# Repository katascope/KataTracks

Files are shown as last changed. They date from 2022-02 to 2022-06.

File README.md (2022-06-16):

# KataTracks
The KataTracks system is three parts: The KataTracks software, the LightSuit, and the LightSuitAngel device.

## KataTracks
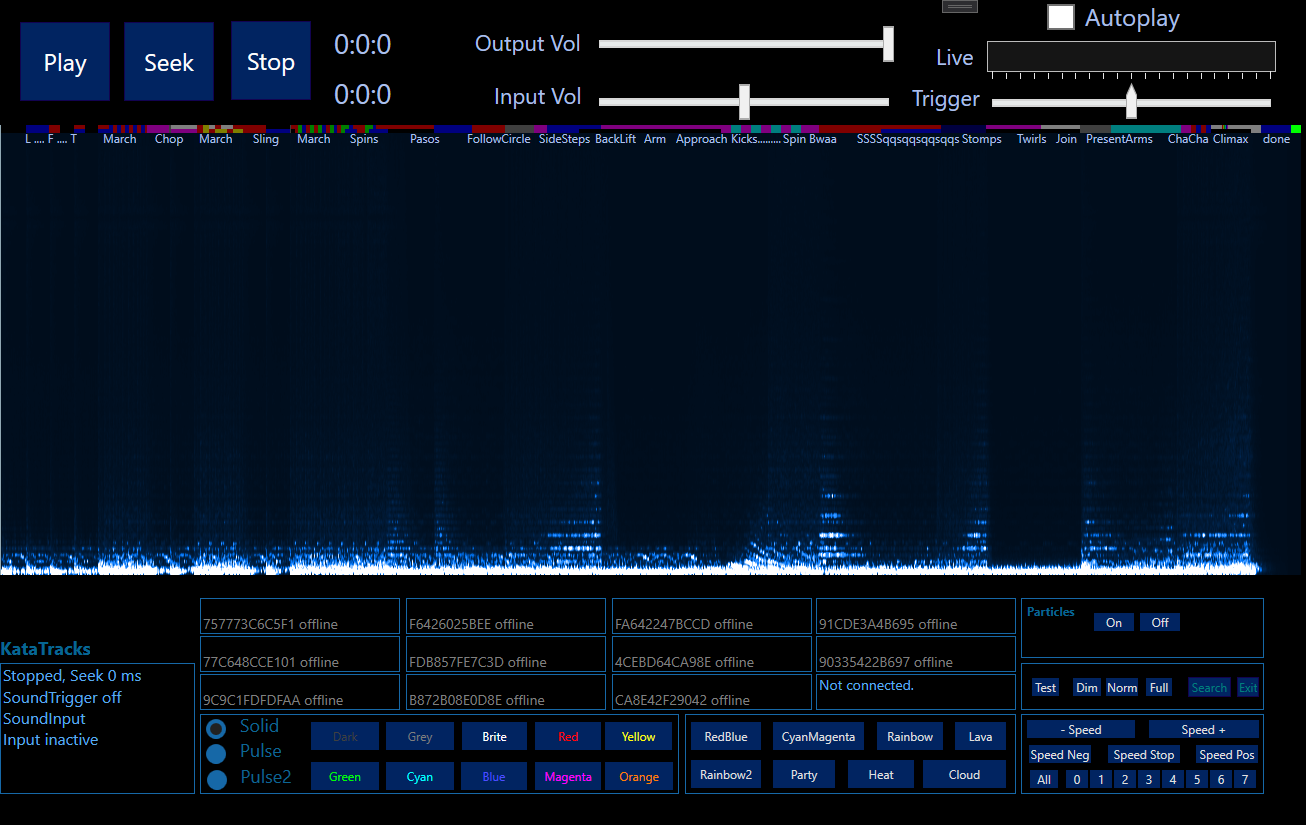
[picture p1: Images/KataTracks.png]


The KataTracks Application provides remote Bluetooth Low Energy (BLE) control over multiple LightSuits.

## LightSuit
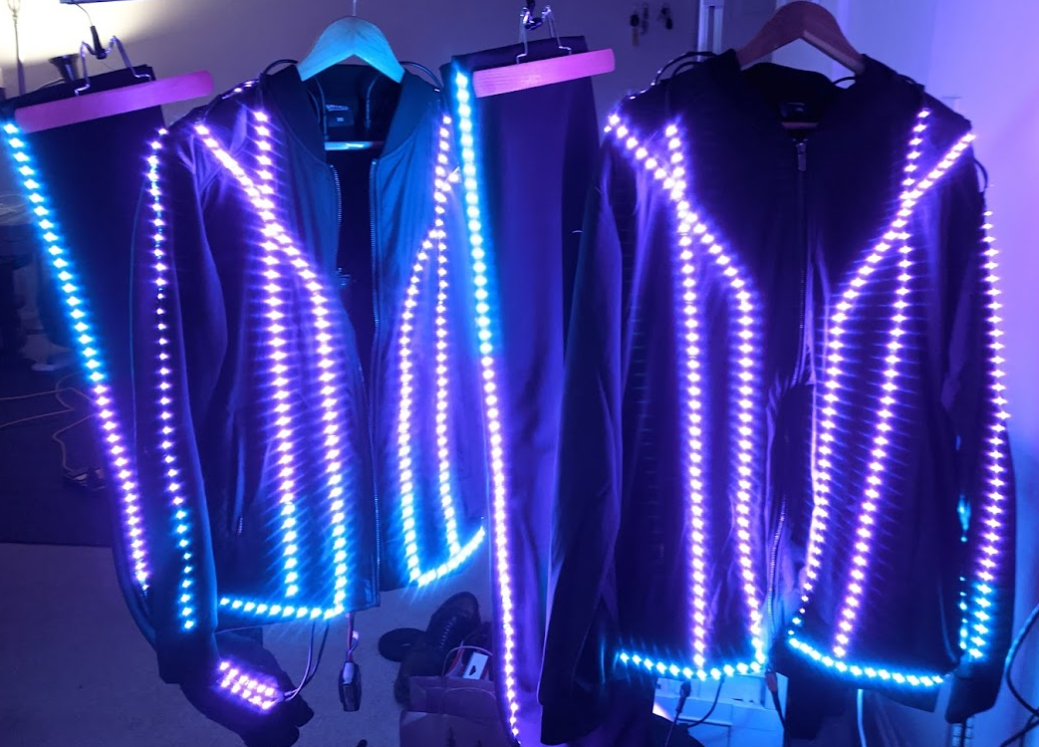
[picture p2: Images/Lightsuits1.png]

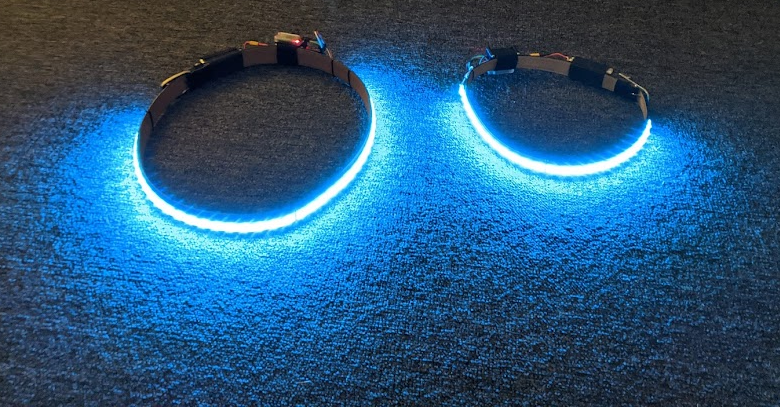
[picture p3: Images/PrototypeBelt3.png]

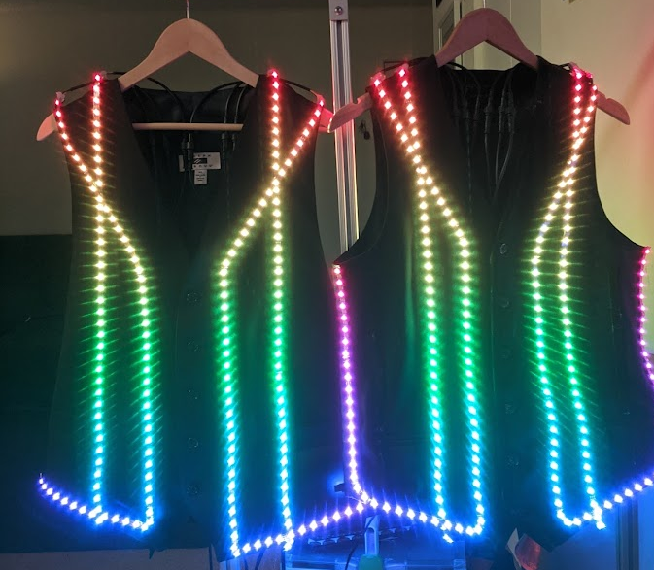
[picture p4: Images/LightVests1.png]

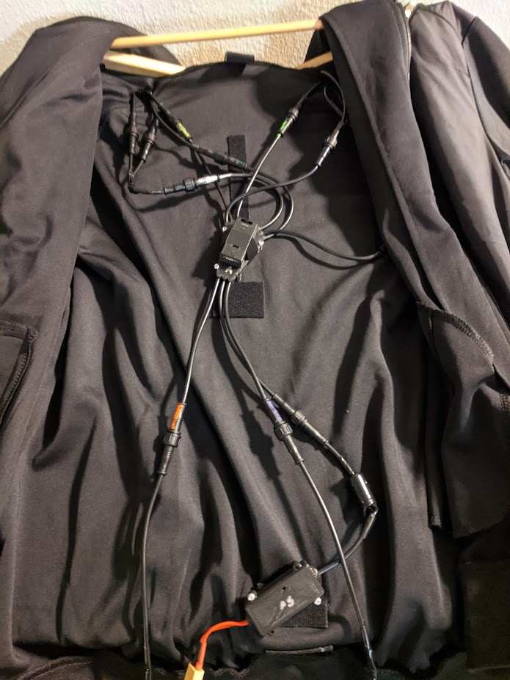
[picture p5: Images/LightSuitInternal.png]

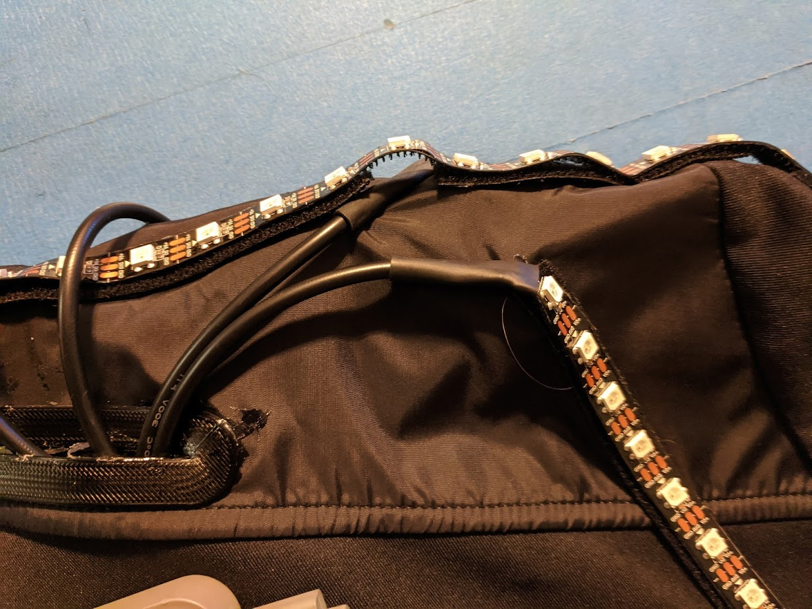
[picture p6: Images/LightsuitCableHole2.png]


Parts:
* BTF-LIGHTING WS2812B RGB 5050SMD Individual Addressable LED
* BTF-LIGHTING 3 Pin Electrical Connector 22AWG IP65 Male Female Connector
* Two-sided Velcro strip attached to suits
* Adhesive Velctro strip attached to LED strips
* Rubberized suit hole

Each LightSuit is a series of individually controlled addressable LED strips and LightSuitAngel. Velcro strips are attached to clothing, then to led strips. The velcro holds the strips together and connect at ends through 3-wire BTF connectors into the LightSuitAngel.

## LightSuitAngel
The LightSuitAngel devices provides 8-channels of control of LightSuit control. A 3d-printed case covers an Arduino Nano BLE device, using NeoPixel to run micro-second timed preprogrammed tracks.

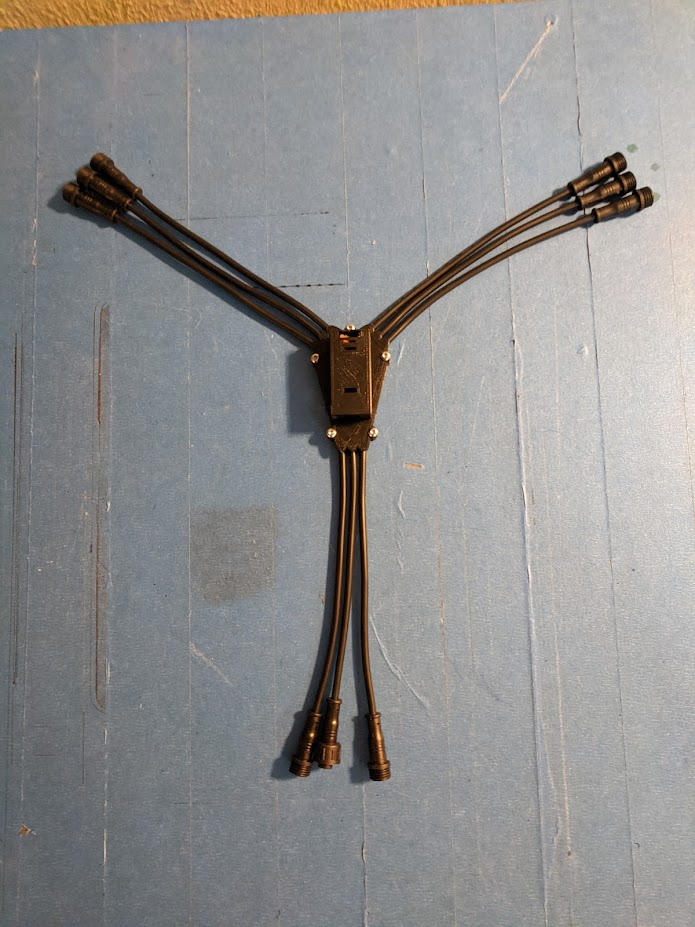
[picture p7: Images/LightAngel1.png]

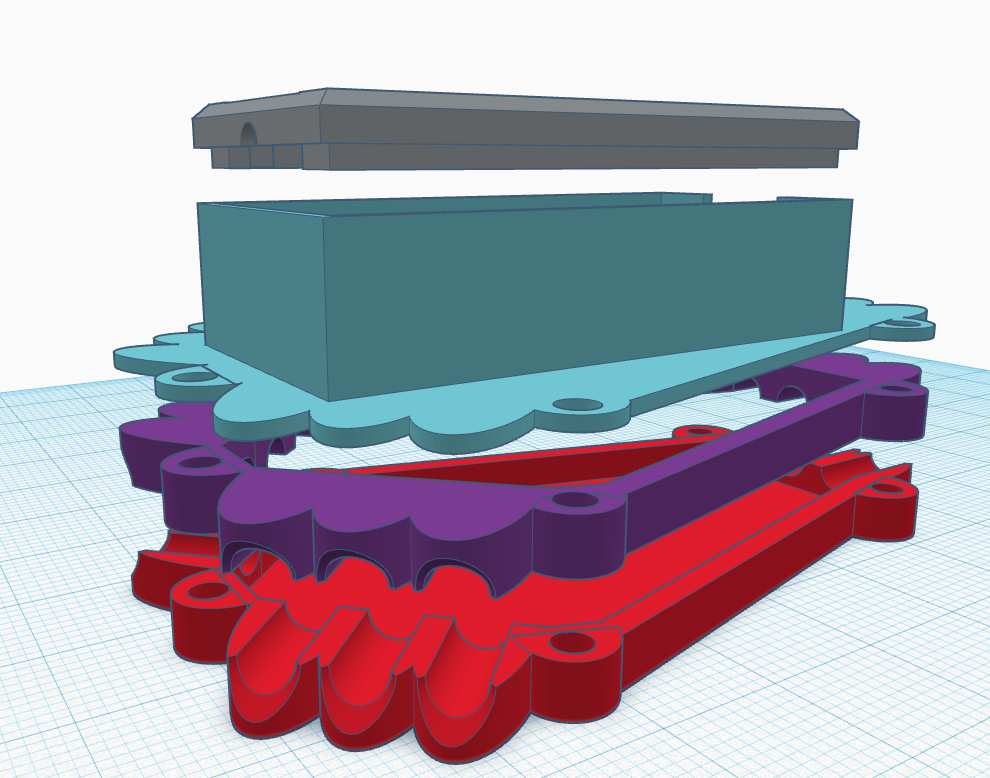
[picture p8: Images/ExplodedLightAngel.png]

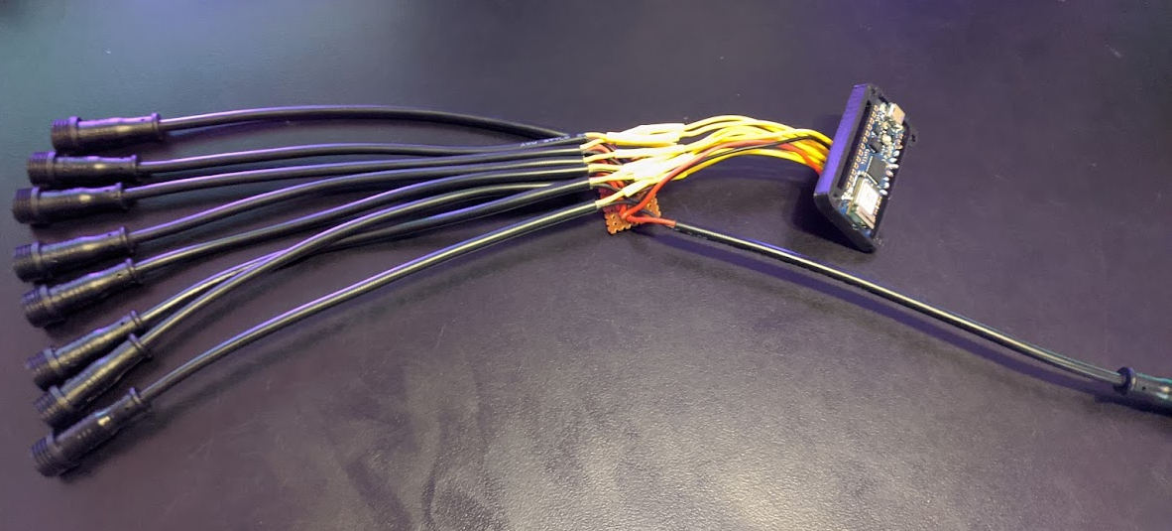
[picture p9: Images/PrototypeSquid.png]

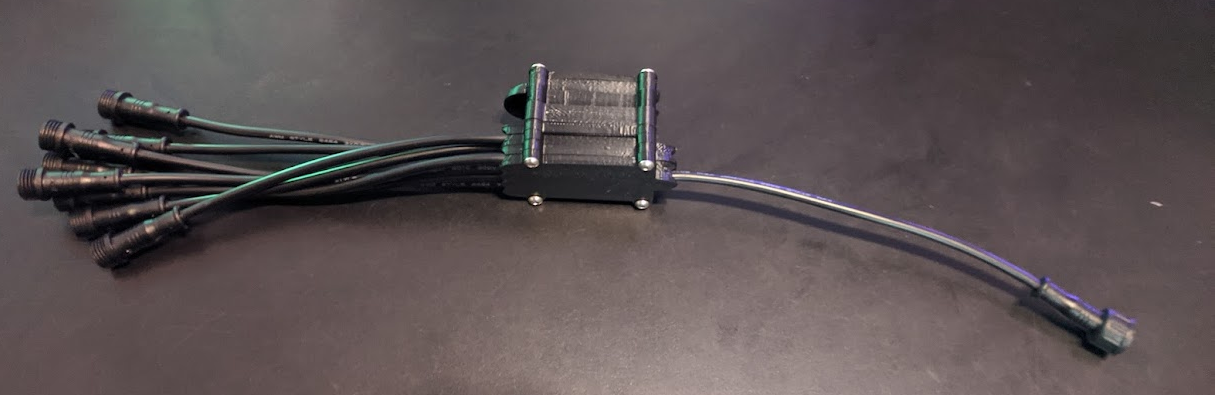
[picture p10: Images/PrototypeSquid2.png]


Parts
* Arduino Nano BLE
* BTF-LIGHTING WS2812B RGB 5050SMD Individual Addressable LED
* BTF-LIGHTING 3 Pin Electrical Connector 22AWG IP65 Male Female Connector
* LM2596S LM2596 Buck Converter 3A DC-DC 3-40V to 1.5-35v DC Voltage Regulator 
* 1000uF 50V Capacitor
* XT60 connector
* 25pcs DIP IC Chip Socket Adaptor
* M3 screws

Other simpler 1-channel devices can also be used with BTF splitters.

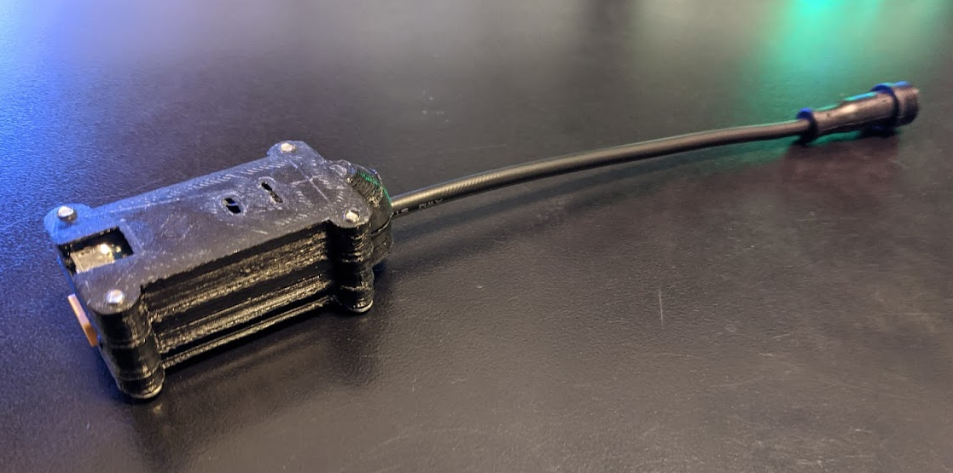
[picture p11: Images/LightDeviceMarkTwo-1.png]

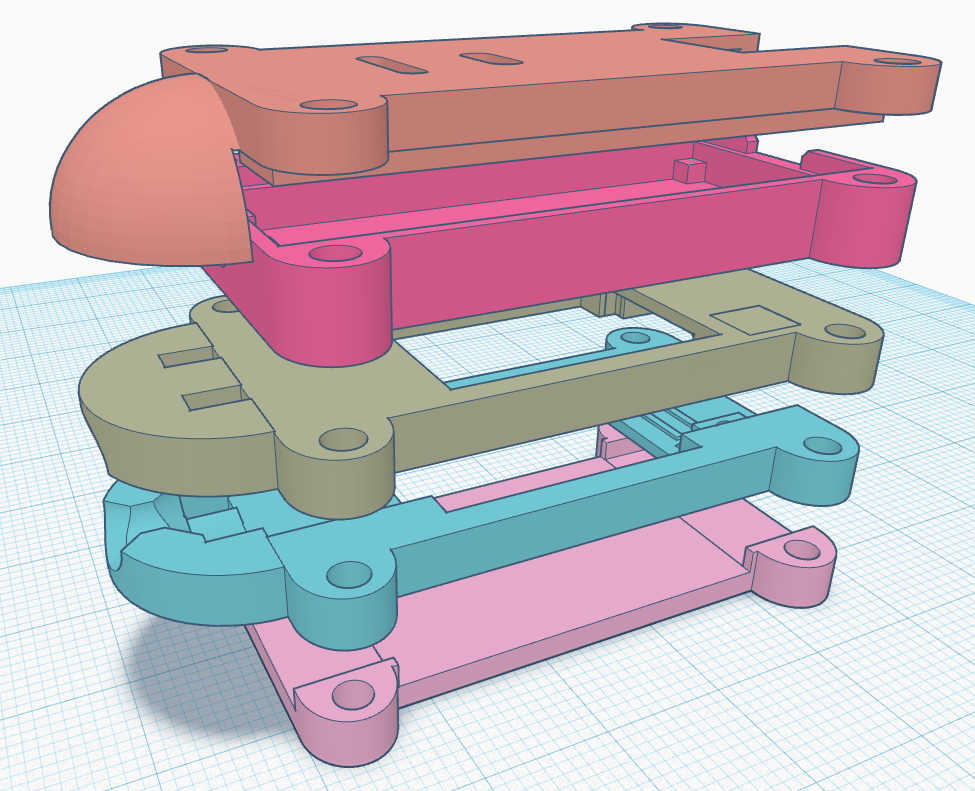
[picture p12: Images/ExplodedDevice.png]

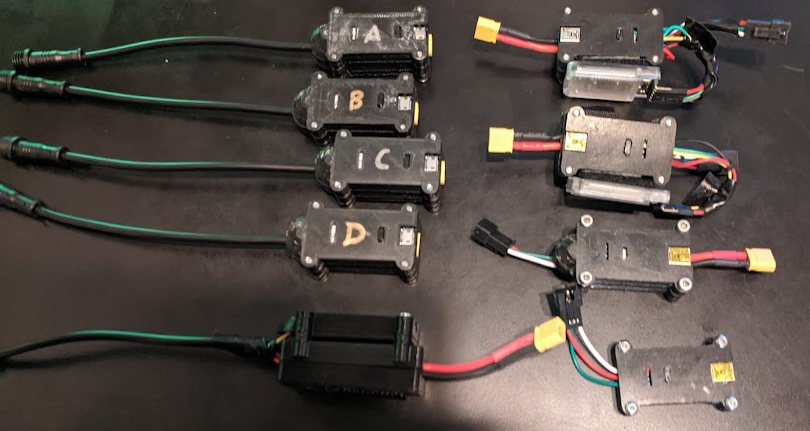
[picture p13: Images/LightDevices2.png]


In combination, the KataTracks system allows for multiple time-synchronized led light-suits to be used for performance dance.

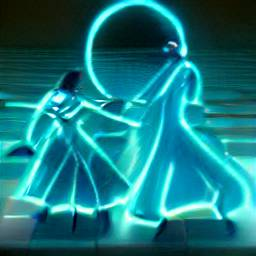
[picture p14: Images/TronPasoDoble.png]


Abandoned ideas:
* Using EL wire, too monochrome of effects.
* Using IMU for colors, too unpredictable during dance.
* Using regular Arduino Nano, Bluetooth modules cumbersome to attach.
* Using Arduino Nano IOT, timing was flaky.
* Playing music to theater, theater will have to provide sound.
* JST 3-wires, connectors have no tension or bend protection.

KataTracks is under the [MIT License](https://opensource.org/licenses/MIT)

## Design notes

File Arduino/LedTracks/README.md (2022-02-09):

# FastLEDTracks
Music Track system for FastLED

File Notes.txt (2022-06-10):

Devices, Bluetooth:
 AT+NAME=Lightsuit#
 AT+UART=9600,0,0
 AT+PSWD=...

Todo:
Build:
 Backup device
 Fix Burnt BEC
Research:
 KataTracks
  Postponed connecting
  "Shimmer test" for pre-show synchronicity
  Multi-threaded Reconnection ability
 Lightsuit
  Extension cables - need newtype connector
  X-hole connector, like leather/rubber?
 Device
  Redesign to protect Bluetooth module

# KataTracks
What it should be: Wireless light-suits precisely synchronized to events in the music.
Lightsuit.. Songtracksuit?

Mark 1 : 
 System: Arduino Nano
 Case: 3d-printed for Nano
 Power: XT30 connection (can adapt to XT60)
 Output: BTF-Lighting Connector
Mark 2 : Wireless
 Wireless: HC-05 Bluetooth
Mark 3
 System: Arduino Nano OR Pro Micro
 Case: 3d-printed for Nano
 Power: XT30 connection (can adapt to XT60)
 Output: BTF-Lighting Connector
 Wireless: HC-05 Bluetooth
Additions:
 Accelerometer
 128x32 OLED display

   Design Criteria:
    Audioreactive : The device must represent the dance music.
    Lead-Follow : The follow device can synchronize with the lead device.
    Simple : The device must be extremely easy to use once setup.
    Reliable : The software must work correctly during the dance.
     Care with overloading bluetooth buffer
     Startup 3 seconds for led safety
    Minimal : The device must strenously optimize RAM usage.
     PROGMEM for Track - Can expand without using RAM
     See: https://www.arduino.cc/reference/en/language/variables/utilities/progmem/
    Configurable : The code must be highly configurable by #DEFINE.
    Recoverable : The device should be able to recover from mistimings.
    Cheap : The device must be low cost and easy to produce.
    Portable : The device must be human wearable and untethered.
    Stable : The device must withstand repeated heavy use dancing.
    Subtle : Indirect lighting for led's, hazed frosted fogged.
    Compatible : The device must maximize use of standards.
     Arduino Nano : Standard microcontroller kit
     WS2811 : Addressable LED wire : Standard 3-wire connectors
     BTF-Lighting Connectors : Addressable 3-wire LED wire connectors
     Also used for power connector into arduino.
     XT-60 Battery connector with D-Sun BEC Voltage convert (3-cell 12v down to 5v)
      or 18650 Battery Shield case using 5-V output
     Thingiverse Case & plans
     ffmpeg for Spectrum Analysis
     HC-05 Bluetooth https://www.evelta.com/blog/instructions-to-set-bluetooth-module-hc05-password-using-arduino/
      AT+NAME?
      AT+NAME="LedLight"
      AT+PSWD="3838"
     Master+Slave BT bindings: https://www.instructables.com/Arduino-Bluetooth-Master-and-Slave-Using-Any-HC-05/
   Tradeoffs:
     Audio track setup does not have to be easy or quick.
     Different arduinos can be used.
     Different forms of power/battery can be used.
     Arduino Micro Pro can be used if possible instead of Arduino Nano
   Aesthetic Criteria:
     Tasteful : Use complex colors, avoid 'rgb rainbow land'
     Smooth : Fading color transitions over palette rotations
     Fade-To interpolated timing so endings match startings
   To create a spectrum analysis for use in creating the events:
     Use ffmpeg with a size of (song length * 10). ex 205 seconds * 10 = 2050x512 as below.
      ex. ffmpeg -i "game.m4a" -lavfi showspectrumpic=s=2050x512:color=4:scale=lin:stop=8000 gameLd.png
   Ideas:
    https://learn.sparkfun.com/tutorials/prototype-wearable-led-dance-harness/all
    https://learn.sparkfun.com/tutorials/motion-controlled-wearable-led-dance-harness
    https://learn.sparkfun.com/tutorials/hackers-in-residence---sound-and-motion-reactivity-for-wearables
   Radio: dw
    NRF24L01 https://www.instructables.com/Arduino-and-NRF24L01/
    RTF433 https://www.instructables.com/RF-315433-MHz-Transmitter-receiver-Module-and-Ardu/
   JY-MCU Bluetooth module communication example for Arduino.
    Connect RX_PIN to TX pin of the module,
    Connect TX_PIN to RX pin of the module.
   Set Bluetooth HC-05

   16k - For a bluetooth-enabled 300-addressableled-driving music-synchronized system

   //Accelerometer: https://electropeak.com/learn/interfacing-mma7361-accelerometer-module-with-arduino/

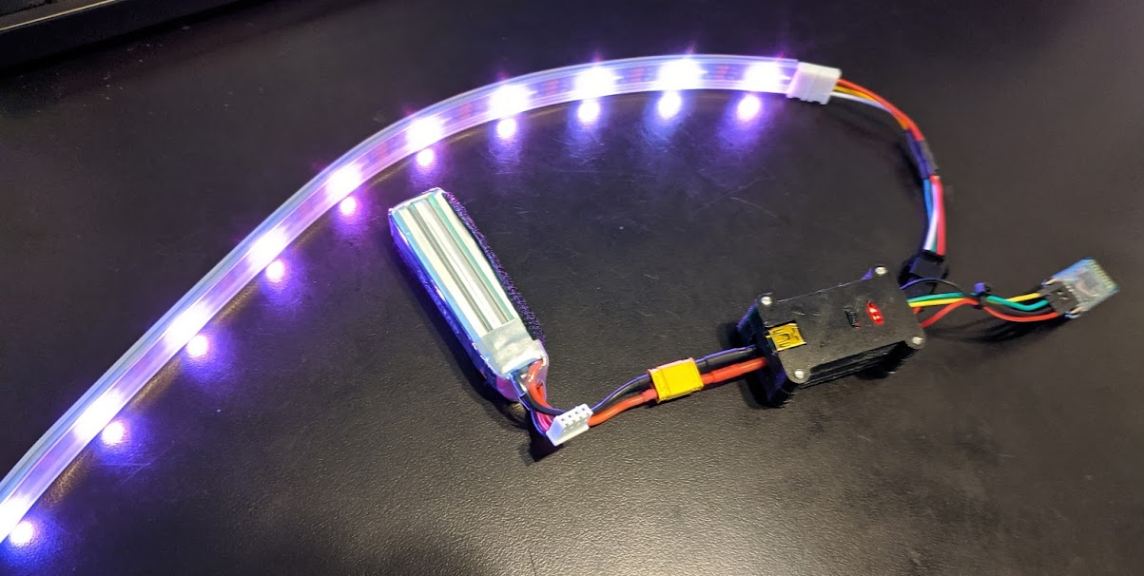
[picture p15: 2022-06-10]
Images/PrototypeBluetooth3.png

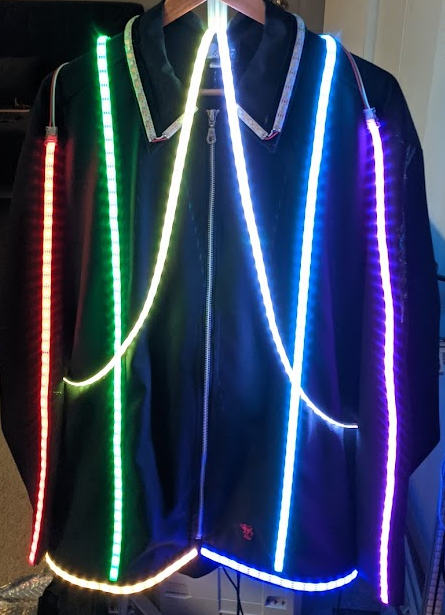
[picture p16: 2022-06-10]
Images/LightDeviceSquid-1.png

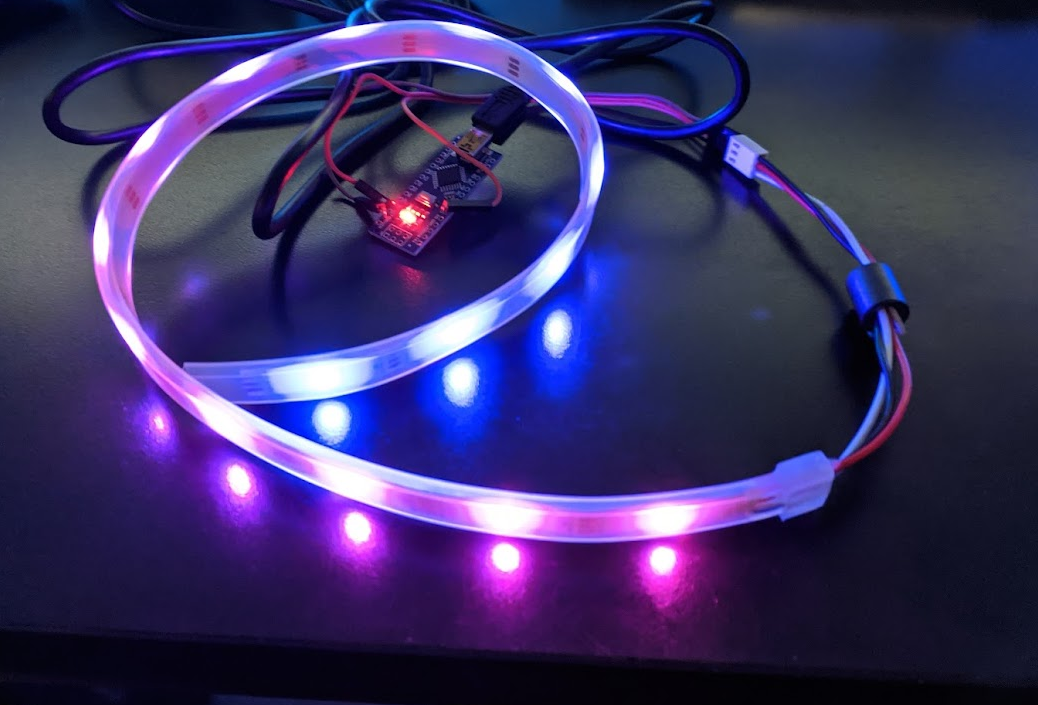
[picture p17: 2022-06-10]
Images/Prototype1.png

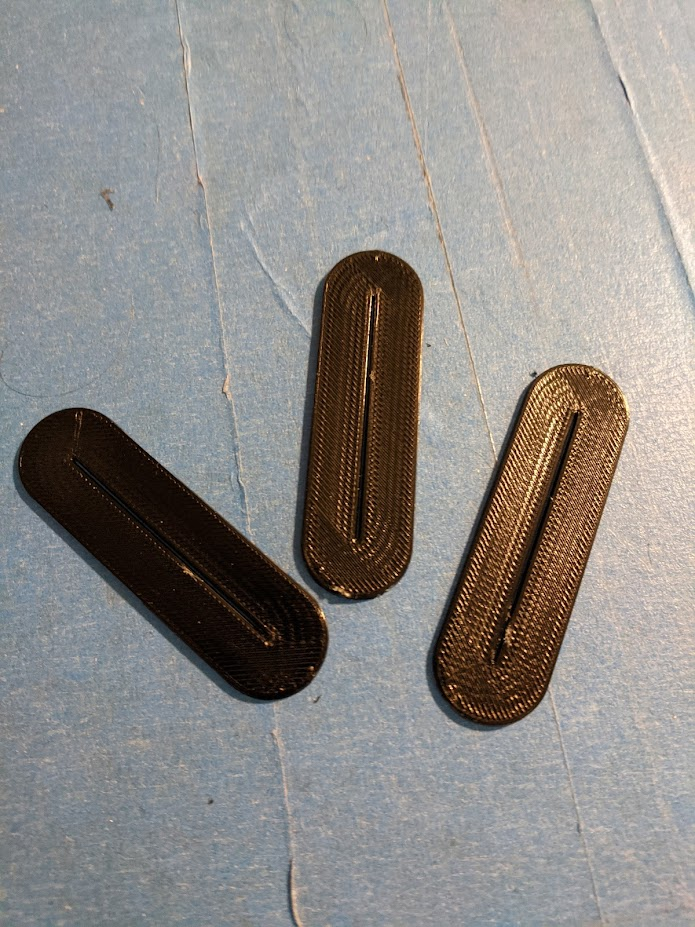
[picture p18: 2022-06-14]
Images/LightSuitCableHole1.png

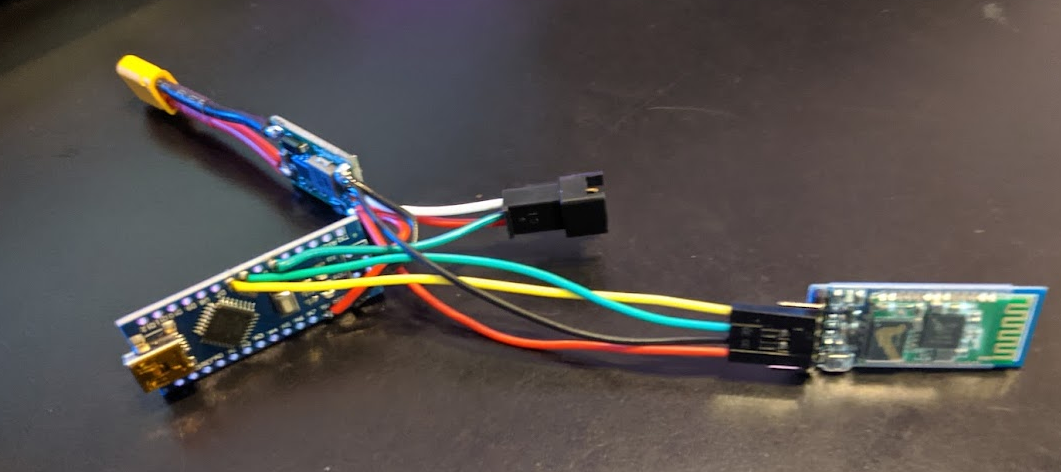
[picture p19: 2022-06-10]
Images/PrototypeBluetooth1.png

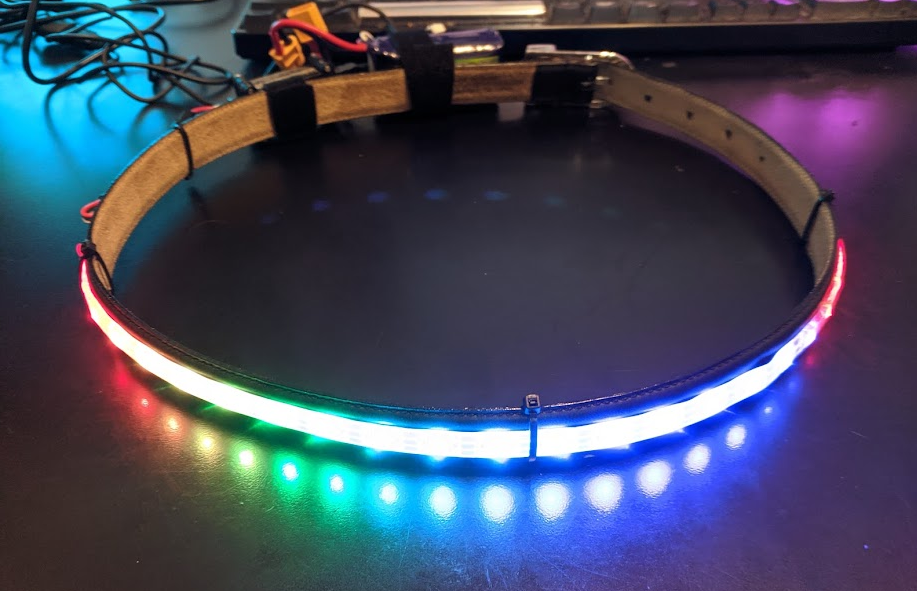
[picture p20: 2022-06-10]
Images/PrototypeBelt2.png

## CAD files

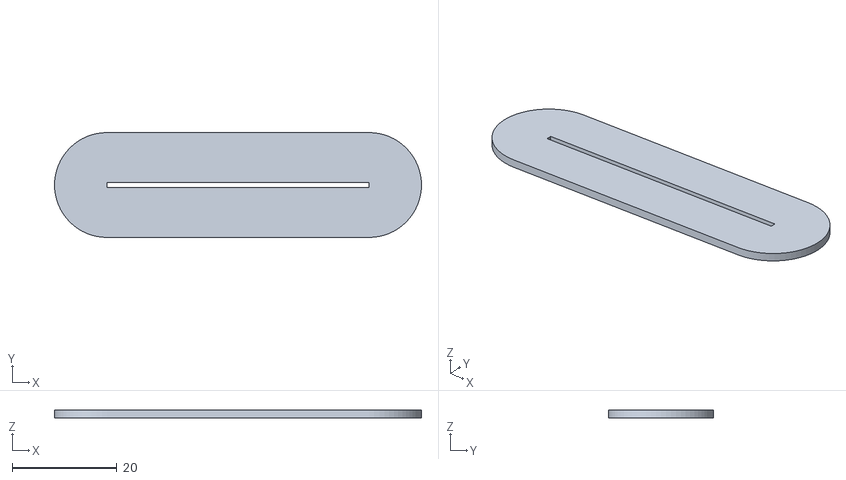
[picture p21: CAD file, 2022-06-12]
Hardware/STL/LightSuitCablePanel.stl
70.0 x 20.0 x 1.50

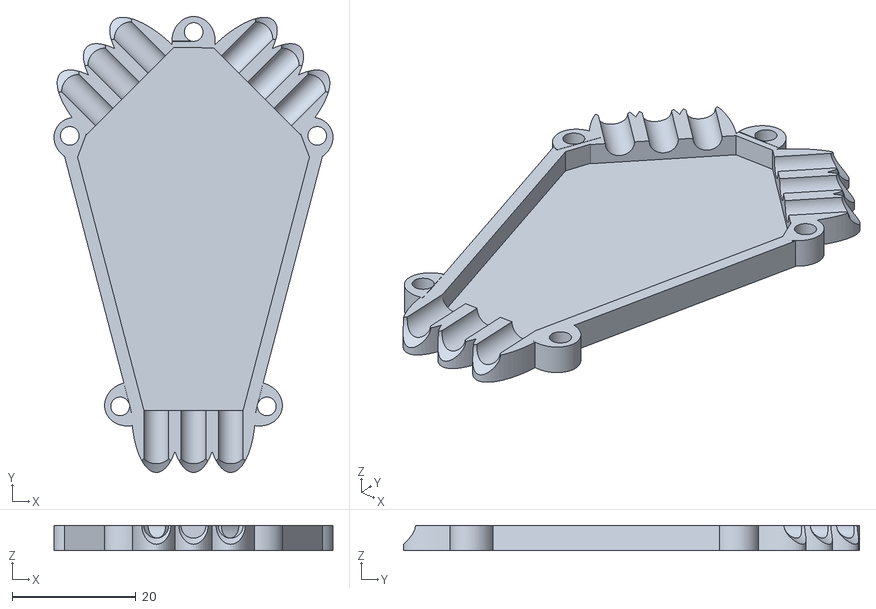
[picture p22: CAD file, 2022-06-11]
Hardware/STL/LightSuitAngel-Base.stl
45.0 x 73.6 x 4.03

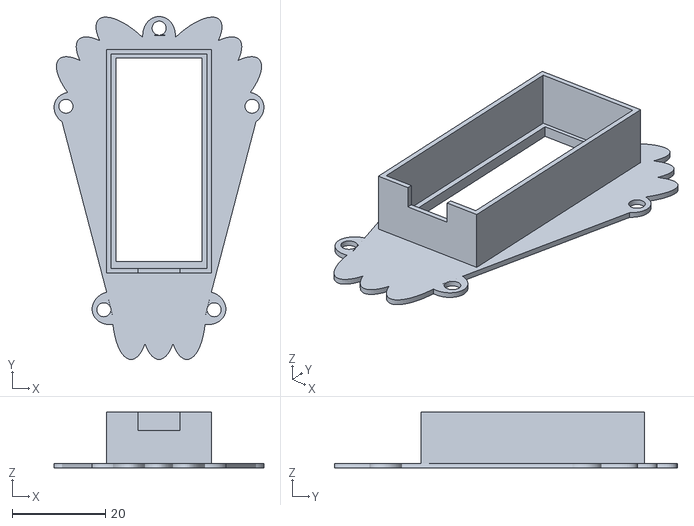
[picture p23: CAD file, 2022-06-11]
Hardware/STL/LightSuitAngel-Case.stl
45.0 x 73.6 x 12.0

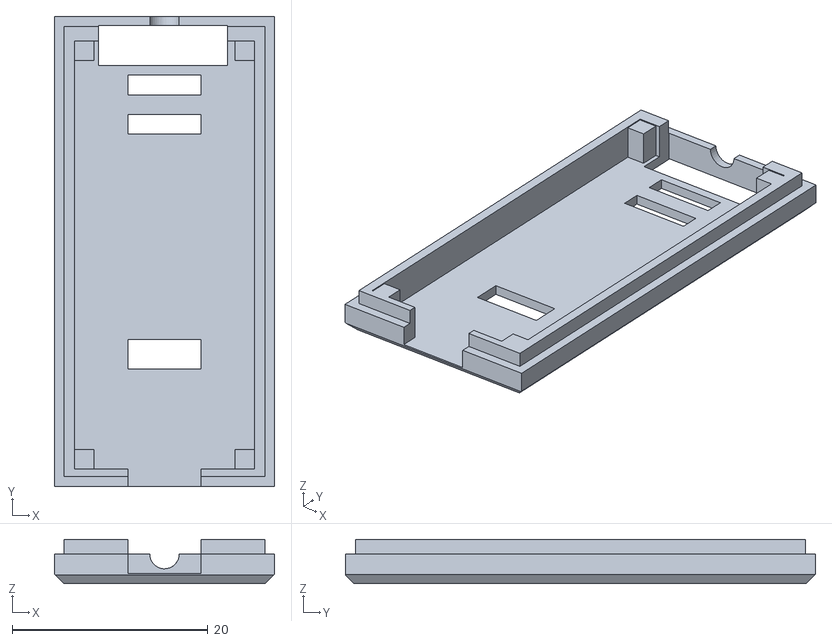
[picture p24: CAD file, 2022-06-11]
Hardware/STL/LightSuitAngel-Lid.stl
22.5 x 48.0 x 4.50

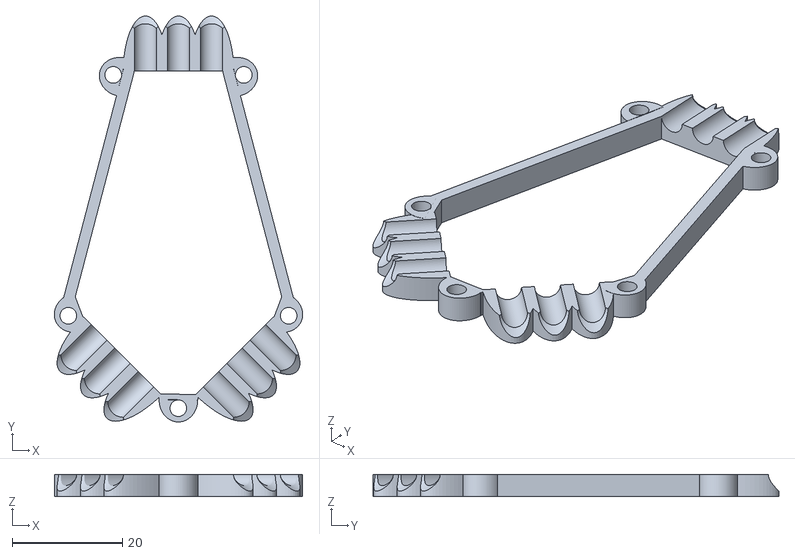
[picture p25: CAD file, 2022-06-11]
Hardware/STL/LightSuitAngel-Grip.stl
45.0 x 73.6 x 4.03

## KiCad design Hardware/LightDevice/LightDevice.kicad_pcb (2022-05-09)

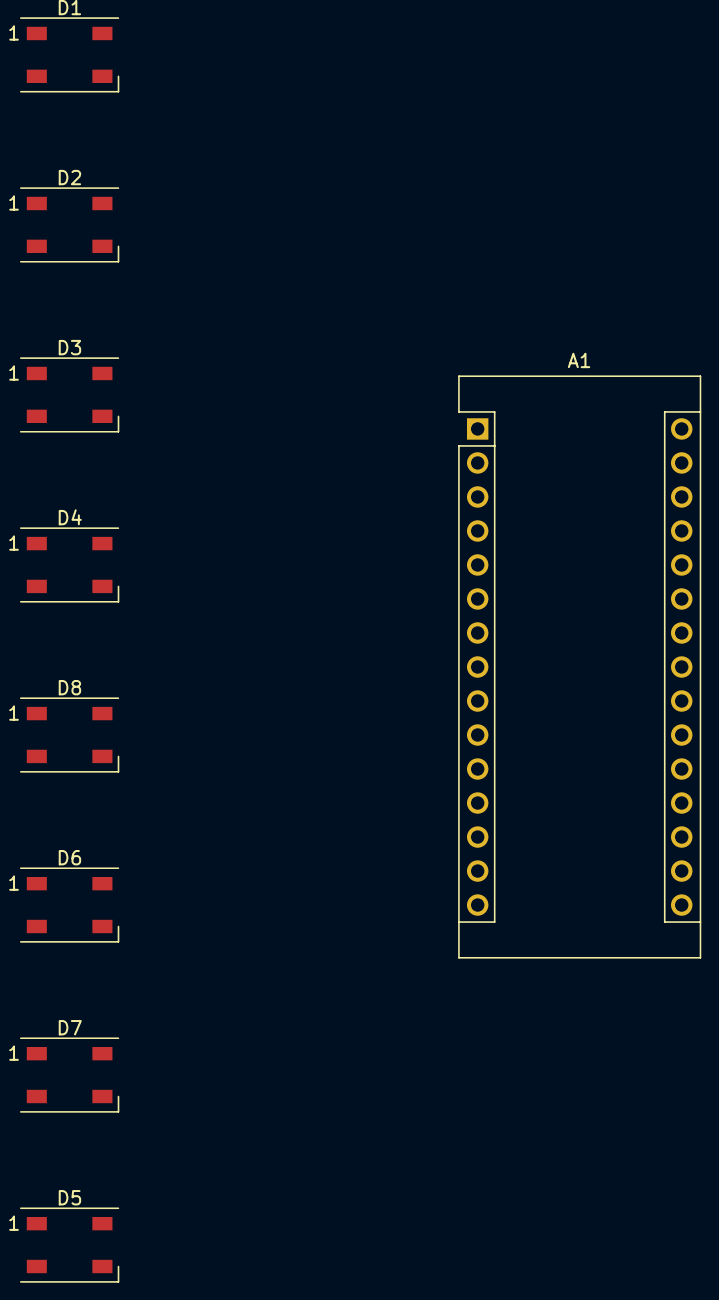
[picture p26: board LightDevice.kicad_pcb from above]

Board: 2 copper layers, 9 parts (0 on the bottom side), 10 nets, no tracks yet.

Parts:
A1: Arduino_Nano_v3.x; Arduino_Nano
D1, D2, D3, D4, D5, D6, D7, D8: WS2812B; LED_WS2812B_PLCC4_5.0x5.0mm_P3.2mm

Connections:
+5V: A1.27 (+5V), D1.3 (VSS), D2.3 (VSS), D3.3 (VSS), D4.3 (VSS), D5.3 (VSS), D6.3 (VSS), D7.3 (VSS), D8.3 (VSS)
GND: A1.29 (GND), D1.1 (VDD), D2.1 (VDD), D3.1 (VDD), D4.1 (VDD), D5.1 (VDD), D6.1 (VDD), D7.1 (VDD), D8.1 (VDD)
unnamed: A1.6 (D3), D1.4 (DIN)
unnamed: A1.7 (D4), D2.4 (DIN)
unnamed: A1.8 (D5), D3.4 (DIN)
unnamed: A1.9 (D6), D4.4 (DIN)
unnamed: A1.10 (D7), D5.4 (DIN)
unnamed: A1.11 (D8), D6.4 (DIN)
unnamed: A1.12 (D9), D7.4 (DIN)
unnamed: A1.13 (D10), D8.4 (DIN)

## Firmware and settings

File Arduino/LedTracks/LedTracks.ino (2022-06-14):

/*Copyright 6/14/2022 github/katascope
Permission is hereby granted, free of charge, to any person obtaining a copy of this software and associated documentation files (the "Software"), to deal in the Software without restriction, including without limitation the rights to use, copy, modify, merge, publish, distribute, sublicense, and/or sell copies of the Software, and to permit persons to whom the Software is furnished to do so, subject to the following conditions:
The above copyright notice and this permission notice shall be included in all copies or substantial portions of the Software.
THE SOFTWARE IS PROVIDED "AS IS", WITHOUT WARRANTY OF ANY KIND, EXPRESS OR IMPLIED, INCLUDING BUT NOT LIMITED TO THE WARRANTIES OF MERCHANTABILITY, FITNESS FOR A PARTICULAR PURPOSE AND NONINFRINGEMENT. IN NO EVENT SHALL THE AUTHORS OR COPYRIGHT HOLDERS BE LIABLE FOR ANY CLAIM, DAMAGES OR OTHER LIABILITY, WHETHER IN AN ACTION OF CONTRACT, TORT OR OTHERWISE, ARISING FROM, OUT OF OR IN CONNECTION WITH THE SOFTWARE OR THE USE OR OTHER DEALINGS IN THE SOFTWARE.*/
// LightDrive : A time-track event system for Addressable LED
// Purpose is for a wearable dance-synchronized lightsuit.
#include "Config.h"
#include "Fx.h"
#include "Track.h"
#include "Cmd.h"
#include "State.h"
#include "Devices.h"
static FxController fxController;

static unsigned long lastTimeDisplay = 0;

void setup() {
  Serial.begin(SERIAL_BAUD_RATE);
  Serial.print(DeviceName);
  Serial.print(F("Serial init: "));
  Serial.println(SERIAL_BAUD_RATE);
  
#if SYSTEM_NANO_33_BLE
  Serial.println(F("System: Arduino Nano 33 BLE"));
#elif SYSTEM_NANO_33_IOT
  Serial.println(F("System: Arduino Nano 33 IOT"));
#elif SYSTEM_UNO
  Serial.println(F("System: Arduino UNO"));
#elif SYSTEM_NANO
  Serial.println(F("System: Arduino Nano"));
#else
  Serial.println(F("System: UNKNOWN"));
#endif

#if ENABLE_MEMORYUSAGE
  Serial.println(F("MemoryUsage"));
  MEMORY_PRINT_STACKSIZE
  MEMORY_PRINT_HEAPSIZE
#endif  

#if ENABLE_NEOPIXEL
  Serial.println(F("Delaying 3 seconds for LEDs."));
  delay( 3000 ); // power-up safety delay
  neopixelSetup();
  for (int strip=0;strip<NUM_STRIPS;strip++)
    for (int led=0;led<fxController.strip[strip]->numleds;led++)
      fxController.strip[strip]->palette[led] = 0;
  Serial.print(F("NeoPixel init: "));
  Serial.print(F(" LEDs on pin "));
  Serial.println(LED_PIN);
#else
  Serial.println(F("No NeoPixel init"));
#endif

#if ENABLE_BLE
  Serial.println(F("BLE init"));
  bleSetup();
#else
  Serial.println(F("No BLE init"));
#endif

  fxController.fxState = STARTUP_STATE;

  if (fxController.fxState == FxState_TestPattern)
  { 
    Serial.println("Setting test pattern.");
    FxEventProcess(fxController, fx_palette_drb);
  }

  if (fxController.fxState == FxState_PlayingTrack)
  {
    fxController.fxTrackEndAction = FxTrackEndAction::LoopAtEnd;
    trackStart(fxController, 0, (unsigned long)(millis() - (signed long)TRACK_START_DELAY), fxController.fxTrackEndAction);
  }
  else Serial.println(F("Ready"));

#if ENABLE_NEOPIXEL
//Display brightness levels
  Serial.print(F("Brightness = { "));
  for (int strip=0;strip<NUM_STRIPS;strip++)
  {
    fxController.strip[strip]->brightness = BRIGHTNESS;
    neopixelSetBrightness(strip,fxController.strip[strip]->brightness);
    Serial.print(fxController.strip[strip]->brightness);
    Serial.print(F(" "));
  }
  Serial.println(F(" }"));
#endif

  Serial.println("Setup complete.");
}

void UpdatePalette()
{
  FxProcessSideFX(fxController);
  
  for (int strip=0;strip<NUM_STRIPS;strip++)
  {
    if ((int)fxController.strip[strip]->fxPaletteUpdateType != 0)
    {
      fxController.strip[strip]->paletteIndex = fxController.strip[strip]->paletteIndex + (fxController.strip[strip]->paletteSpeed * fxController.strip[strip]->paletteDirection);
      if (fxController.strip[strip]->paletteIndex >= fxController.strip[strip]->numleds)
        fxController.strip[strip]->paletteIndex -= fxController.strip[strip]->numleds;
      if (fxController.strip[strip]->paletteIndex < 0)
        fxController.strip[strip]->paletteIndex = fxController.strip[strip]->numleds - 1;
    }
#if ENABLE_NEOPIXEL
    neopixelSetPalette(strip, fxController.strip[strip]->numleds, fxController.strip[strip]->palette, fxController.strip[strip]->paletteIndex);
#endif    
  }

}

void loop()
{

//Display status once a second
  unsigned long t =  millis();
  if (t - lastTimeDisplay > 1000)//delay to let bluetooth get data
  {      
    if (fxController.fxState != FxState_PlayingTrack)
      FxDisplayStatus(fxController);      
    lastTimeDisplay = t;
  }
  
  while (Serial.available())  
    UserCommandInput(fxController, Serial.read());

#if ENABLE_BLE
  blePoll(fxController);
#endif

  State_Poll(fxController);

  bool needsUpdate = false;
  for (int strip=0;strip<NUM_STRIPS;strip++)
  {
    if (fxController.strip[strip]->fxPaletteUpdateType == FxPaletteUpdateType::Once
    || fxController.strip[strip]->fxPaletteUpdateType == FxPaletteUpdateType::Always
    || fxController.IsAnimating())
      needsUpdate = true;
  }
  
  if (fxController.fxState == FxState_PlayingTrack || needsUpdate)
  {
    unsigned long t =  millis();
    if (t - fxController.lastTimeLedUpdate > UPDATE_DELAY)//delay to let bluetooth get data(fastled issue)
    {
      UpdatePalette();
      
      fxController.lastTimeLedUpdate = t;
      
      for (int strip=0;strip<NUM_STRIPS;strip++)
      {
        if (fxController.strip[strip]->fxPaletteUpdateType == FxPaletteUpdateType::Once)
          fxController.strip[strip]->fxPaletteUpdateType = FxPaletteUpdateType::Done;
      }
    }
  }
}

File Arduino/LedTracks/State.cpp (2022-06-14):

/*Copyright 6/14/2022 github/katascope
Permission is hereby granted, free of charge, to any person obtaining a copy of this software and associated documentation files (the "Software"), to deal in the Software without restriction, including without limitation the rights to use, copy, modify, merge, publish, distribute, sublicense, and/or sell copies of the Software, and to permit persons to whom the Software is furnished to do so, subject to the following conditions:
The above copyright notice and this permission notice shall be included in all copies or substantial portions of the Software.
THE SOFTWARE IS PROVIDED "AS IS", WITHOUT WARRANTY OF ANY KIND, EXPRESS OR IMPLIED, INCLUDING BUT NOT LIMITED TO THE WARRANTIES OF MERCHANTABILITY, FITNESS FOR A PARTICULAR PURPOSE AND NONINFRINGEMENT. IN NO EVENT SHALL THE AUTHORS OR COPYRIGHT HOLDERS BE LIABLE FOR ANY CLAIM, DAMAGES OR OTHER LIABILITY, WHETHER IN AN ACTION OF CONTRACT, TORT OR OTHERWISE, ARISING FROM, OUT OF OR IN CONNECTION WITH THE SOFTWARE OR THE USE OR OTHER DEALINGS IN THE SOFTWARE.*/
#include "Config.h"
#include "Devices.h"
#include "State.h"
#include "FxCore.h"
#include "Fx.h"
#include "Track.h"

void State_Poll_TestPattern(FxController &fxc)
{
#if ENABLE_NEOPIXEL

  FxEventProcess(fxc, fx_strip_all);
  FxEventProcess(fxc, fx_transition_fast);
  //Serial.println("Polling test pattern");
    for (int strip=0;strip<NUM_STRIPS;strip++)
    {
      fxc.strip[strip]->paletteSpeed = 0;
      fxc.strip[strip]->fxPaletteUpdateType = FxPaletteUpdateType::Always;
    }

    FxEventProcess(fxc, fx_strip_all);//fx_strip + LEDS_0);
    FxEventProcess(fxc, fx_palette_rainbow);
#if !ENABLE_MULTISTRIP
    FxEventProcess(fxc, fx_palette_half);
#endif    
    neopixelSetPalette(0, fxc.strip[0]->numleds, fxc.strip[0]->palette, fxc.strip[0]->paletteIndex);
    neopixelSetPixel(0, 0, CRGB_WHITE);
    
#if ENABLE_MULTISTRIP    
    FxEventProcess(fxc, fx_strip + LEDS_1);
    FxEventProcess(fxc, fx_palette_red);
    neopixelSetPalette(1, fxc.strip[1]->numleds, fxc.strip[1]->palette, fxc.strip[1]->paletteIndex);
    
    FxEventProcess(fxc, fx_strip + LEDS_2);
    FxEventProcess(fxc, fx_palette_yellow);
    neopixelSetPalette(2, fxc.strip[2]->numleds, fxc.strip[2]->palette, fxc.strip[2]->paletteIndex);
    
    FxEventProcess(fxc, fx_strip + LEDS_3);
    FxEventProcess(fxc, fx_palette_green);
    neopixelSetPalette(3, fxc.strip[3]->numleds, fxc.strip[3]->palette, fxc.strip[3]->paletteIndex);
    
    FxEventProcess(fxc, fx_strip + LEDS_4);
    FxEventProcess(fxc, fx_palette_cyan);
    neopixelSetPalette(4, fxc.strip[4]->numleds, fxc.strip[4]->palette, fxc.strip[4]->paletteIndex);
    
    FxEventProcess(fxc, fx_strip + LEDS_5);
    FxEventProcess(fxc, fx_palette_blue);
    neopixelSetPalette(5, fxc.strip[5]->numleds, fxc.strip[5]->palette, fxc.strip[5]->paletteIndex);
    
    FxEventProcess(fxc, fx_strip + LEDS_6);
    FxEventProcess(fxc, fx_palette_magenta);
    neopixelSetPalette(6, fxc.strip[6]->numleds, fxc.strip[6]->palette, fxc.strip[6]->paletteIndex);
    
    FxEventProcess(fxc, fx_strip + LEDS_7);
    FxEventProcess(fxc, fx_palette_orange);
    neopixelSetPalette(7, fxc.strip[7]->numleds, fxc.strip[7]->palette, fxc.strip[7]->paletteIndex);
#endif    
    FxEventProcess(fxc, fx_strip_all);

    for (int strip=0;strip<NUM_STRIPS;strip++)
    {
        fxc.strip[strip]->palette[0] = CRGB_ORANGE;    
        fxc.strip[strip]->initialPalette[0] = CRGB_ORANGE;
        fxc.strip[strip]->nextPalette[0] = CRGB_ORANGE;
        int nl = fxc.strip[strip]->numleds;
        fxc.strip[strip]->palette[nl-1] = CRGB_ORANGE;    
        fxc.strip[strip]->initialPalette[nl-1] = CRGB_ORANGE;
        fxc.strip[strip]->nextPalette[nl-1] = CRGB_ORANGE;
    }
#endif    
}

void CopyFromNext(FxController &fxc, int strip, int first, int last)
{
  if (last >= fxc.strip[strip]->numleds)
   last = fxc.strip[strip]->numleds;
  if (first < 0)
   first = 0;
  
  if (first < last)
    for (int i = first;i<last; i++)
      fxc.strip[strip]->palette[i] = fxc.strip[strip]->nextPalette[i];
  else
    for (int i = first;i>=last;i--)
      fxc.strip[strip]->palette[i] = fxc.strip[strip]->nextPalette[i];
}

void CopyFromPrev(FxController &fxc, int strip, int first, int last)
{
  if (last >= fxc.strip[strip]->numleds)
   last = fxc.strip[strip]->numleds;
  if (first < 0)
   first = 0;
  
  if (first < last)
    for (int i = first;i<last; i++)
      fxc.strip[strip]->palette[i] = fxc.strip[strip]->initialPalette[i];
  else
    for (int i = first;i>=last;i--)
      fxc.strip[strip]->palette[i] = fxc.strip[strip]->initialPalette[i];
}

void PrintPalette(FxController &fxc)
{
  int limit = 4;
  Serial.print(F(" ini("));     
  for (int i=0;i<limit;i++)
  {
    Serial.print(fxc.strip[0]->initialPalette[i], HEX);
    Serial.print(F(" "));
  }
  Serial.print(F("), ")); 
  Serial.print(F(" pal("));
  for (int i=0;i<limit;i++)
  {
    Serial.print(fxc.strip[0]->palette[i], HEX);
    Serial.print(F(" "));
  }
  Serial.print(F(")")); 
  Serial.print(F(" next("));
  for (int i=0;i<limit;i++)
  {
    Serial.print(fxc.strip[0]->nextPalette[i], HEX);
    Serial.print(F(" "));
  }
  Serial.print(F(")"));   
}
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

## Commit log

2022-02-09 User interface improvements
    Logs for program, bluetooth, including prototype trackview
2022-02-09 Full enabling and test of combined lead/follow devices, with skip
2022-02-10 Displaying feedback from bluetooth devices in log
2022-02-13 Universalized bluetooth devices to 'Lightsuit' search
2022-02-18 Port of FastLedTracks to LedTracks, to support NeoPixel
2022-02-19 Major refactor and fixes
    [BLE.cpp, Commands.cpp, Config.h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]
2022-02-20 True up allowing both BT and BLE devices in KataTracks
2022-02-21 Major LedTracks cleanup
2022-02-21 Fixup of palette update types, resolves pos and neg wipe issues
    [Cmd.cpp, Config.h, Fx.cpp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]
2022-02-21 Test track
2022-02-22 End to end test of 2 ble and 2 bt simultaneous devices
2022-04-26 Updates to volume ui and to main track
2022-04-28 UI upgrades, button by color
2022-04-29 New pulse2 type and track improvements
2022-04-30 Addition of IMU palette event, ble connection log cleanup, and improved track
2022-05-03 Track climax improvement and dance notation inside katatracks ui
2022-05-03 Additions : new speed_rst type tor reset palette index, major track improvements, katatracks sends go to black message on track stop
    [Fx.cpp, FxCore.cpp, FxCore.h]
2022-05-05 Track improvements, Support for Arduino Nano IOT, and predefs for more devices
2022-05-06 pulse and pulse2 cmds, track upgrades, show brightness in ard serial, brightness to 25
2022-05-06 Major track improvements, TimeCodeGen tool
2022-05-06 Track Decoder
2022-05-07 More multistrip led support, with bitmasking for track selection
2022-05-08 KiCad schematic for Light Device
    [LightDevice.kicad_pcb, LightDevice.kicad_sch]
2022-05-08 LightDevice into Hardware folder
    [LightDevice.kicad_pcb, LightDevice.kicad_sch]
2022-05-09 More support for multistrip
    [LightDevice.kicad_pcb, LightDevice.kicad_sch]
2022-05-09 Bug fixes to multistrip
    [Config.h, Devices.cpp, LedTracks.ino]
2022-05-10 Big cleanup, purged mic and imu, more multistrip support.
2022-05-10 More cleanup and proper functional multistrip bitmasks, example track to test
2022-05-11 Major rework to support multistrips with their own palettes and fx
    [Cmd.cpp, Devices.cpp, Fx.cpp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]
2022-05-11 Major improvement to track decoder visualizer, Volume slider to 100
2022-05-12 Practice ready code and track improvements
2022-05-16 Track improvements for multistrip, Test button in katatracks for laying out squids & angels
2022-05-16 Brightness commands reimplemented, brightness buttons in katatracks, track improvements for multistrip
2022-05-16 Macroization of track forms
2022-05-17 More track improvements
2022-05-25 Better lead and follow multitrack track support
2022-05-25 Tuned multistrip lead and follow different track
2022-05-26 Massive track improvements, more angel presets
2022-05-30 Track making proper use of wipe inout and outin
2022-05-30 Major track update
2022-05-30 Random wipe type, more track upgrades
2022-05-31 Low brightness control, quad view of devices
2022-06-01 Bugfixes for ui and commands. Full feature works now.
    [Cmd.cpp, Config.h, Fx.cpp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]
2022-06-02 Implementation of particle effects for tracks, track mod to support them, simplified katatracks device display
2022-06-04 Led strip sizing for both led suits
2022-06-08 Further led sizing for follow
2022-06-09 More led strip sizing for suits, backside needed more
2022-06-10 Schematic and history images
    [LightDevice.kicad_sch]
2022-06-10 Removal of old arduino code
2022-06-11 Removal of old images, addition of STL files for angel
    [LightSuitAngel-Base.stl, LightSuitAngel-Case.stl, LightSuitAngel-Grip.stl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]
2022-06-11 Exploded light device view
2022-06-11 Panel for lightsuits to pass cable through
    [LightSuitCablePanel.stl]
2022-06-12 Track tweak, jacket size tweaks
2022-06-14 Track improvements, angel isolation
2022-06-16 Track finalizaton
2022-06-28 Minor track improvement.
